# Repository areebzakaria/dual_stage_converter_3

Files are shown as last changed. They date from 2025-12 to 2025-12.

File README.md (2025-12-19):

# Dual-Stage Buck Converter (44V to 12V & 5V)

This project features a high-efficiency dual-stage DC-DC buck converter designed using the **Texas Instruments LMR36506 synchronous regulator**.  
The board is optimized for a compact **40mm x 40mm footprint**, focusing on robust thermal management and EMI shielding.

---

## Technical Specifications
- **Input Voltage:** 44V DC (Nominal)  
- **Stage 1 Output:** 12V DC @ 600mA  
- **Stage 2 Output:** 5V DC @ 600mA (cascaded from 12V rail)  
- **Regulator IC:** LMR36506 (RPE Package - 9-Pin VQFN)  
- **Switching Frequency:** High frequency for reduced inductor size  

---

## Hardware Features

### 1. Thermal Management
Since the Stage 1 regulator drops a significant voltage (44V → 12V), heat dissipation is critical.
- **Thermal Vias:** An array of 0.25mm vias is placed directly on the IC's center thermal pad (Pin 9) to conduct heat to the bottom layer.  
- **Ground Plane:** A solid copper pour on the bottom layer acts as a primary heat sink and EMI shield.  

### 2. PCB Layout Optimization
- **Compact Footprint:** Entire design fits within a 40mm × 40mm area.  
- **High-Voltage Safety:** Optimized trace clearances (0.2mm) to handle the 44V input safely.  
- **Power Flow:** Linear layout from left (Input) to right (Output) with thick 0.8mm–1.0mm power traces.  
- **Connectors:** Standard 2.54mm pitch headers for easy lab probing and integration.  

---

## Project Goals
- Deliver a compact, efficient dual-stage buck converter for high-voltage input applications.  
- Ensure robust thermal management and EMI shielding for reliable operation.  
- Provide a lab-friendly design with standard connectors and safe clearances.  

---

## License
This project is released under the MIT License. See [LICENSE](LICENSE) for details.

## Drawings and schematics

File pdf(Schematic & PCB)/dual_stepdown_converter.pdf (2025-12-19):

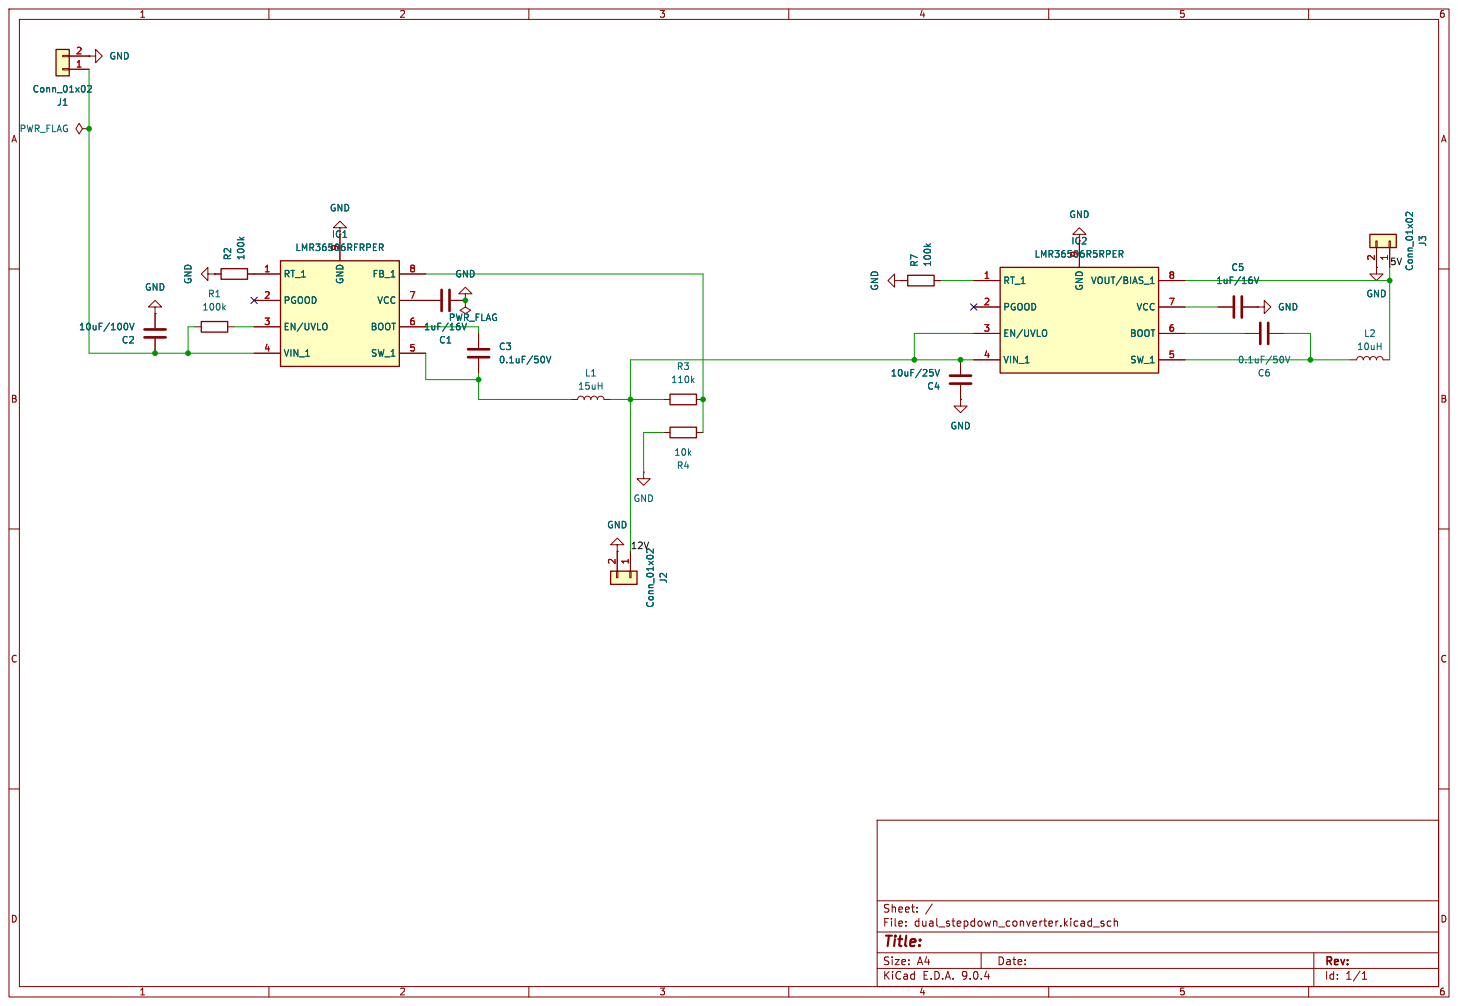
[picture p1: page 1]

9 FB_1 8 VCC 7 BOOT 6 SW_1 5 GND GND R2 100k

1 J3 Conn_01x02 RT_1 1 PGOOD 2 EN/UVLO 3 VIN_1 4 GND

Id: 1/1 Title: File: dual_stepdown_converter.kicad_sch Sheet: /

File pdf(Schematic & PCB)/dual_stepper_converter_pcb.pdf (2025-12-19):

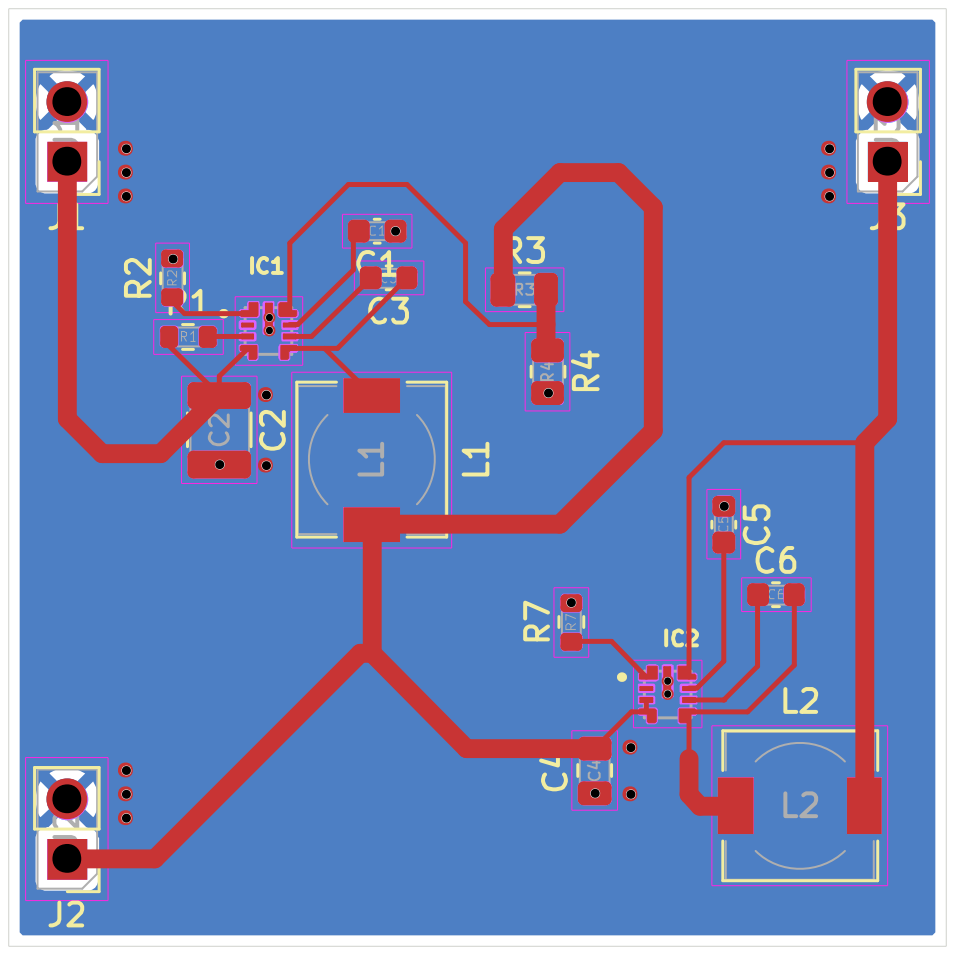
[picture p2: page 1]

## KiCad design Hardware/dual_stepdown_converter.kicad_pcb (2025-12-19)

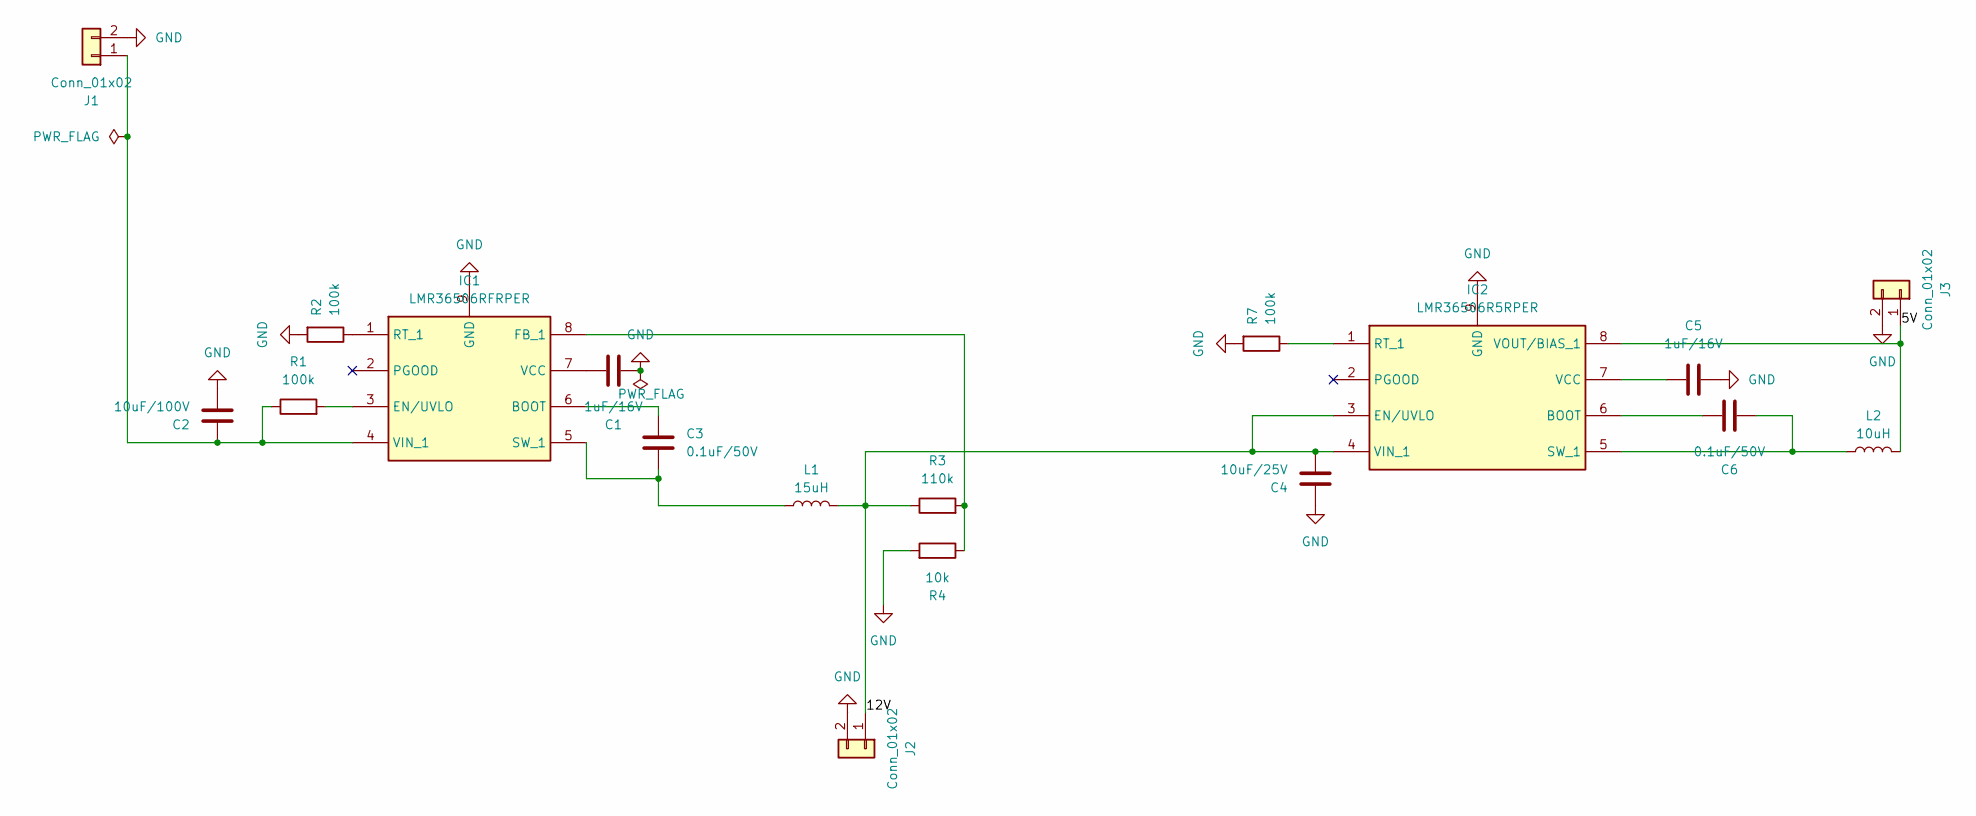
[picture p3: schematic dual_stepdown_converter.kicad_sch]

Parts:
C1, C5: 1uF/16V; C_0603_1608Metric
C2: 10uF/100V; C_1210_3225Metric
C3, C6: 0.1uF/50V; C_0603_1608Metric
C4: 10uF/25V; C_0805_2012Metric
IC1: LMR36506RFRPER; CONV_LMR36503MSC5RPERQ1; Mouser Part Number 595-LMR36506RFRPER
IC2: LMR36506R5RPER; CONV_LMR36503MSC5RPERQ1; Mouser Part Number 595-LMR36506R5RPER
J1, J2, J3: Conn_01x02; PinHeader_1x02_P2.54mm_Vertical
L1: 15uH; L_6.3x6.3_H3
L2: 10uH; L_6.3x6.3_H3
R1, R2, R7: 100k; R_0603_1608Metric
R3: 110k; R_0805_2012Metric
R4: 10k; R_0805_2012Metric

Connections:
/5V: IC2.8 (VOUT/BIAS_1), J3.1, L2.2
/12V: C4.2, IC2.3 (EN/UVLO), IC2.4 (VIN_1), J2.1, L1.2, R3.1
GND: C1.1, C2.2, C4.1, C5.1, IC1.9 (GND), IC2.9 (GND), J1.2, J2.2, J3.2, R2.2, R4.2, R7.2
unnamed: C3.2, IC1.6 (BOOT)
unnamed: IC1.3 (EN/UVLO), R1.2
unnamed: IC1.8 (FB_1), R3.2, R4.1
unnamed: IC1.1 (RT_1), R2.1
unnamed: C3.1, IC1.5 (SW_1), L1.1
unnamed: C1.2, IC1.7 (VCC)
unnamed: C2.1, IC1.4 (VIN_1), J1.1, R1.1
unnamed: C6.1, IC2.6 (BOOT)
unnamed: IC2.1 (RT_1), R7.1
unnamed: C6.2, IC2.5 (SW_1), L2.1
unnamed: C5.2, IC2.7 (VCC)

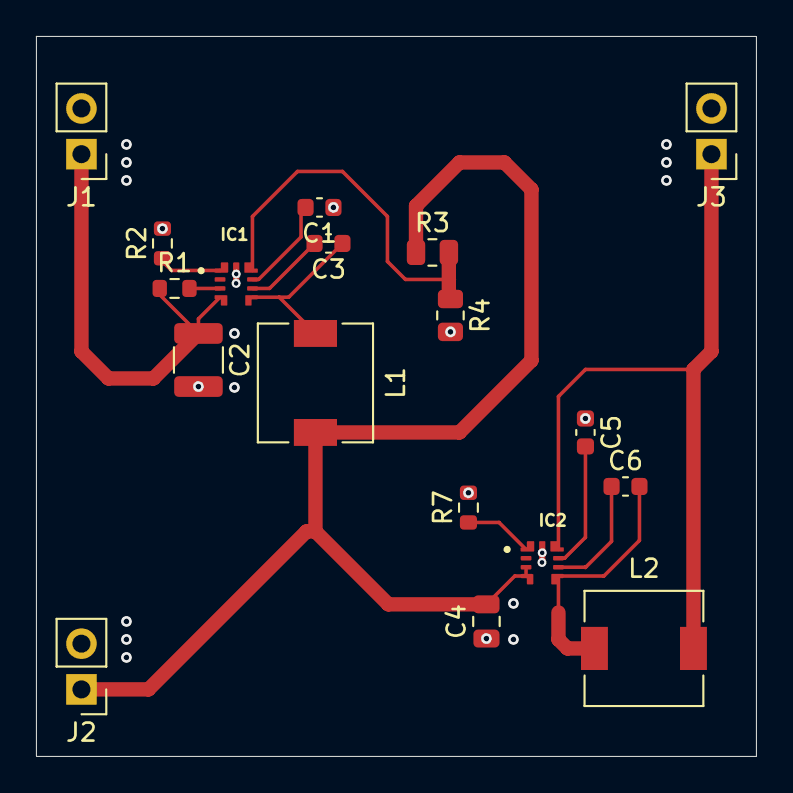
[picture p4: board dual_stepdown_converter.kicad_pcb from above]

Board: 2 copper layers, 40.0 x 40.0 mm, 18 parts (0 on the bottom side), 14 nets.
